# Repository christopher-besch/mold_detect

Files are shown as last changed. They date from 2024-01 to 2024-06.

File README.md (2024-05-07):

# mold_detect

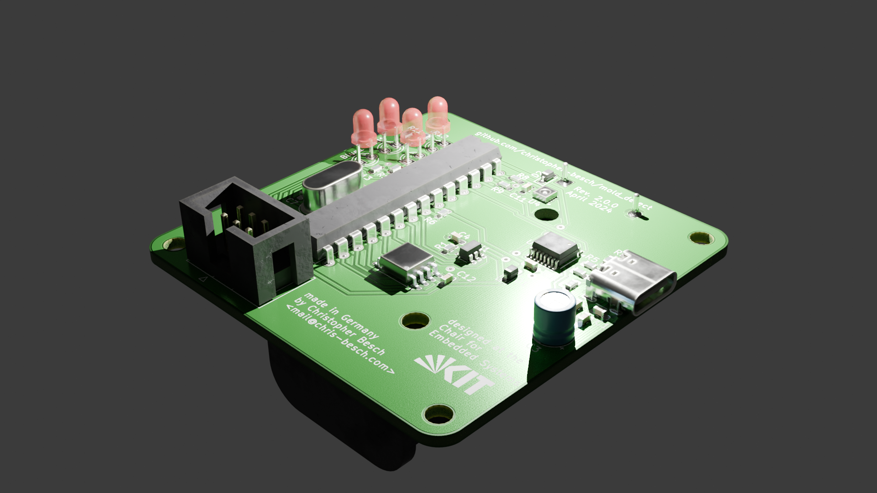
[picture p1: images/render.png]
3D render


Warn residents of mold-friendly atmosphere and log opened windows.

This project is being developed in AVR_C on an Atmega328p.
It provides:
- Temperature, Humidity Logging (every minute with flash storage for two years)
- LED warning to motivate the opening of windows or turnign on of heaters
- Serial terminal via USB-C
- ~5uA power consumption at 3V battery power

The PCB is designed in KiCad and manufactured by Aisler.

# Parts
- [TPL5010](https://www.digikey.de/de/products/detail/texas-instruments/TPL5010DDCR/5119105)
- [2 AAA Battery pack](https://www.digikey.de/de/products/detail/keystone-electronics/2468/303817)
- [SHT30](https://www.digikey.de/de/products/detail/sensirion-ag/SHT30-DIS-B2-5KS/5872250)
- [W25Q128JVSIQ](https://www.digikey.de/de/products/detail/winbond-electronics/W25Q128JVSIQ-TR/5803944)
- [FT230XS](https://www.digikey.de/en/products/detail/ftdi-future-technology-devices-international-ltd/FT230XS-R/3029141)
- [USB4105](https://www.digikey.de/en/products/detail/gct/USB4105-GF-A/11198441)

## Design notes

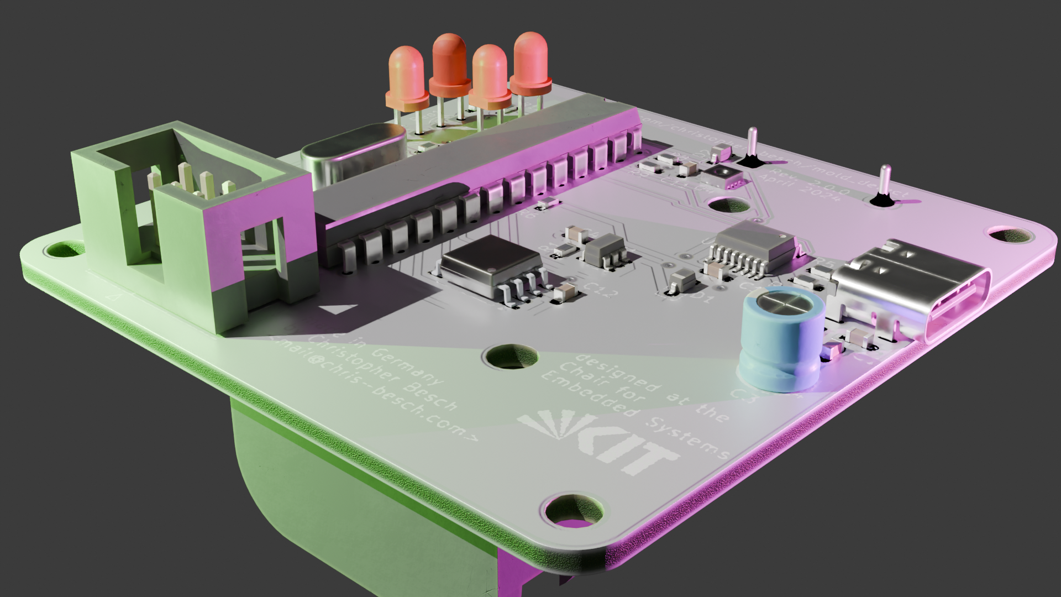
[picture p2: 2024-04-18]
images/color_render.png

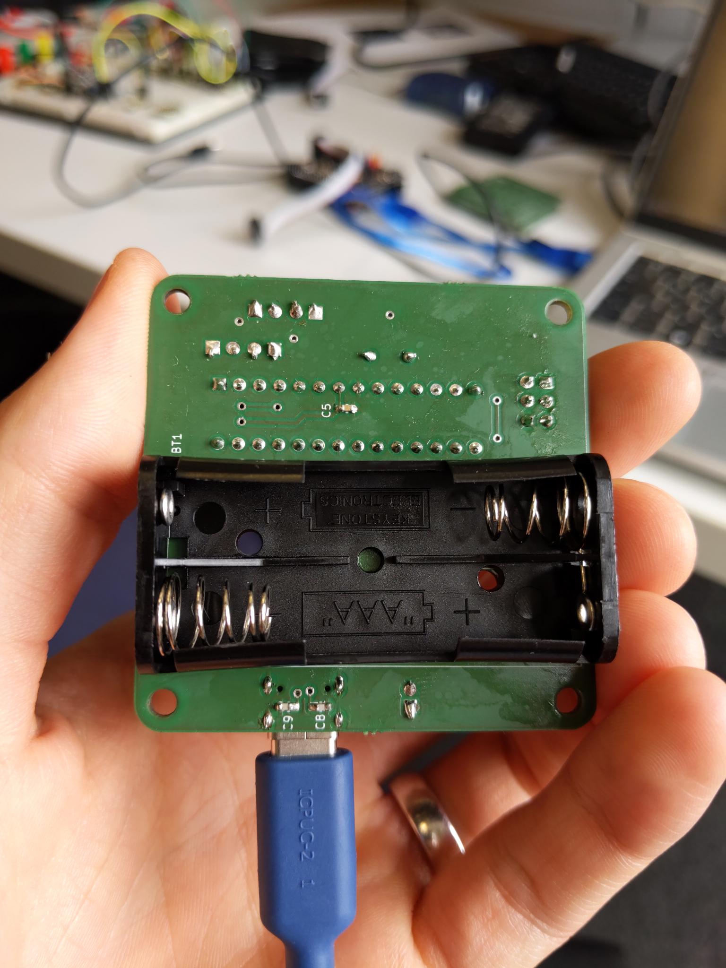
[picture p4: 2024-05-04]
images/back.jpeg

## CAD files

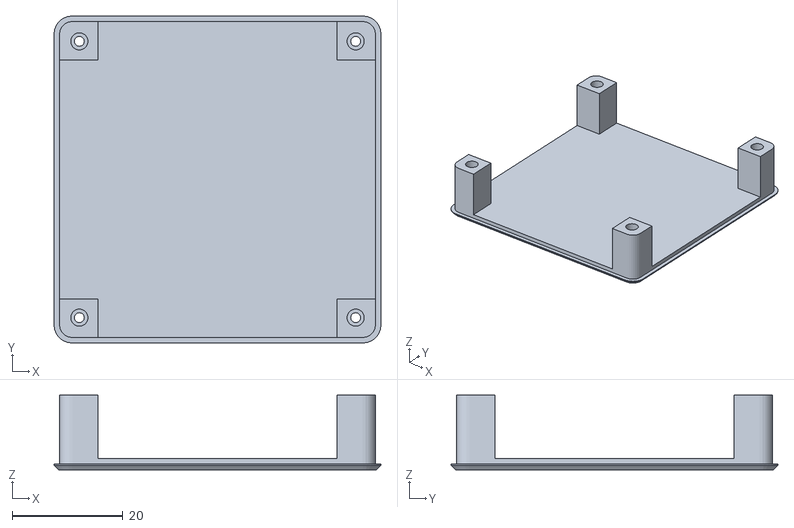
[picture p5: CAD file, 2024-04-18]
casing/bottom.stl
59.2 x 59.2 x 13.5

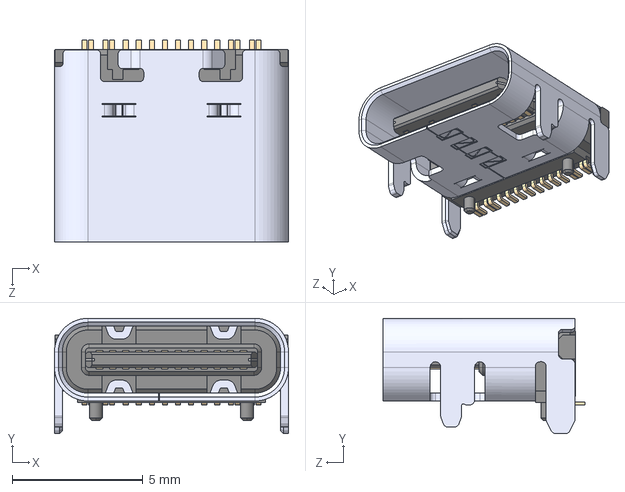
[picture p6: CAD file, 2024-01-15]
models/USB4105-GF-A.step
8.94 x 4.41 x 7.71 mm

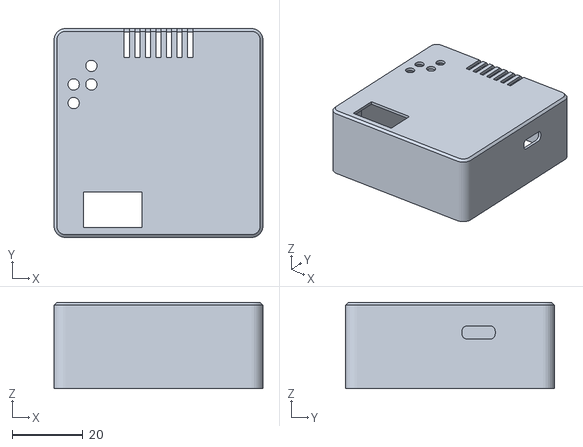
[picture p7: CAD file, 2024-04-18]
casing/top.stl
59.2 x 59.2 x 24.4

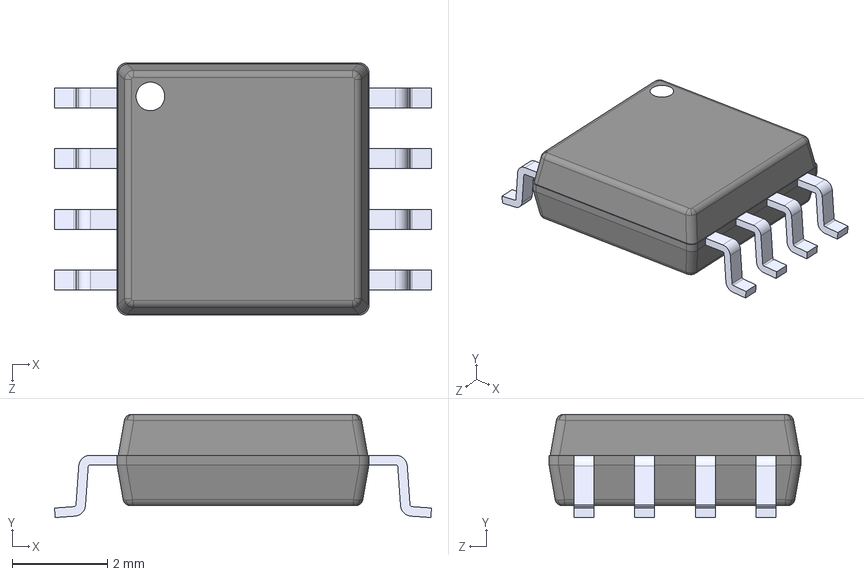
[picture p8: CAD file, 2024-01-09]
models/W25Q128JVSIQ_TR.step
7.90 x 2.16 x 5.28 mm

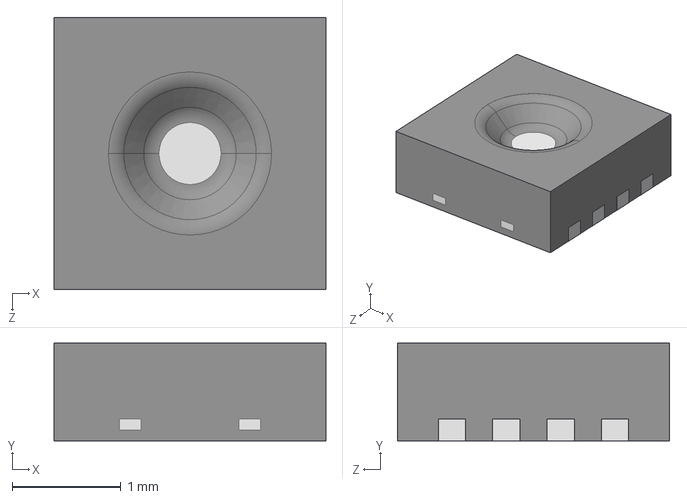
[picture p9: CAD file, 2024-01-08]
models/SHT30-DIS-B2.5KS.step
2.50 x 0.901 x 2.50 mm

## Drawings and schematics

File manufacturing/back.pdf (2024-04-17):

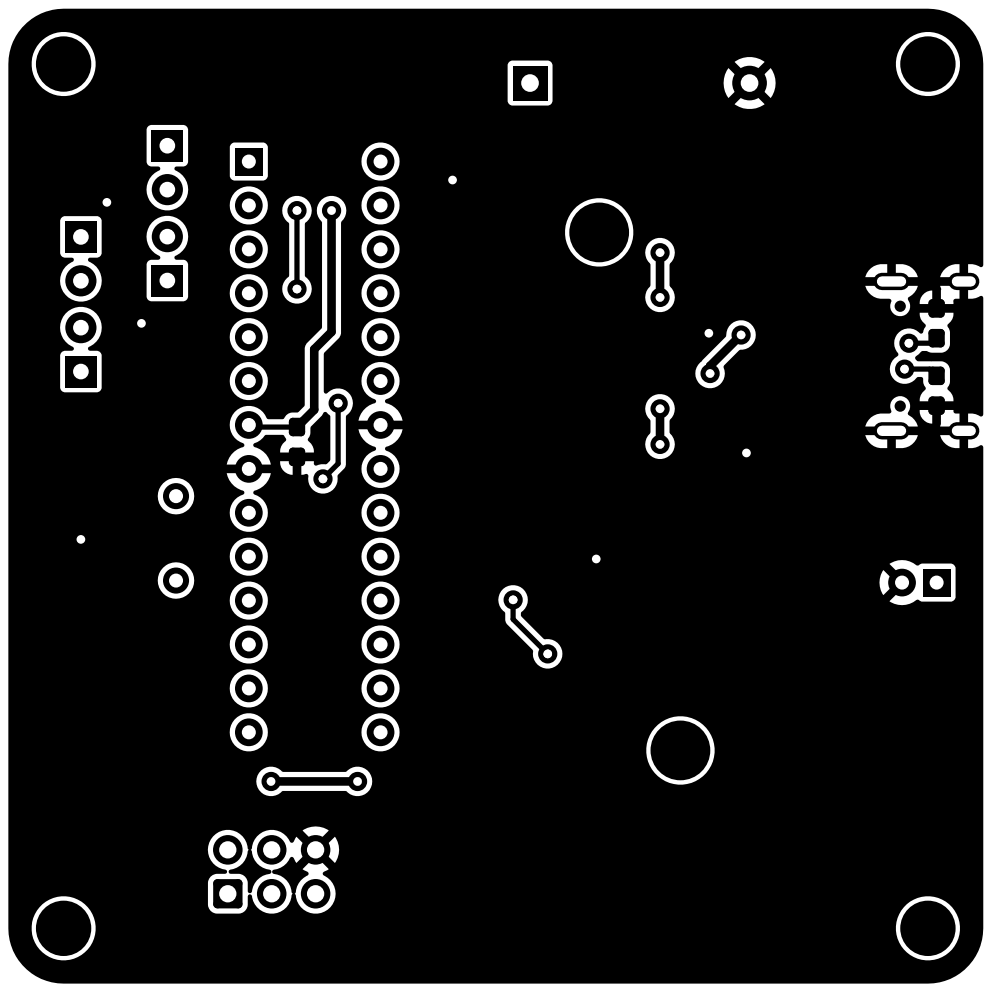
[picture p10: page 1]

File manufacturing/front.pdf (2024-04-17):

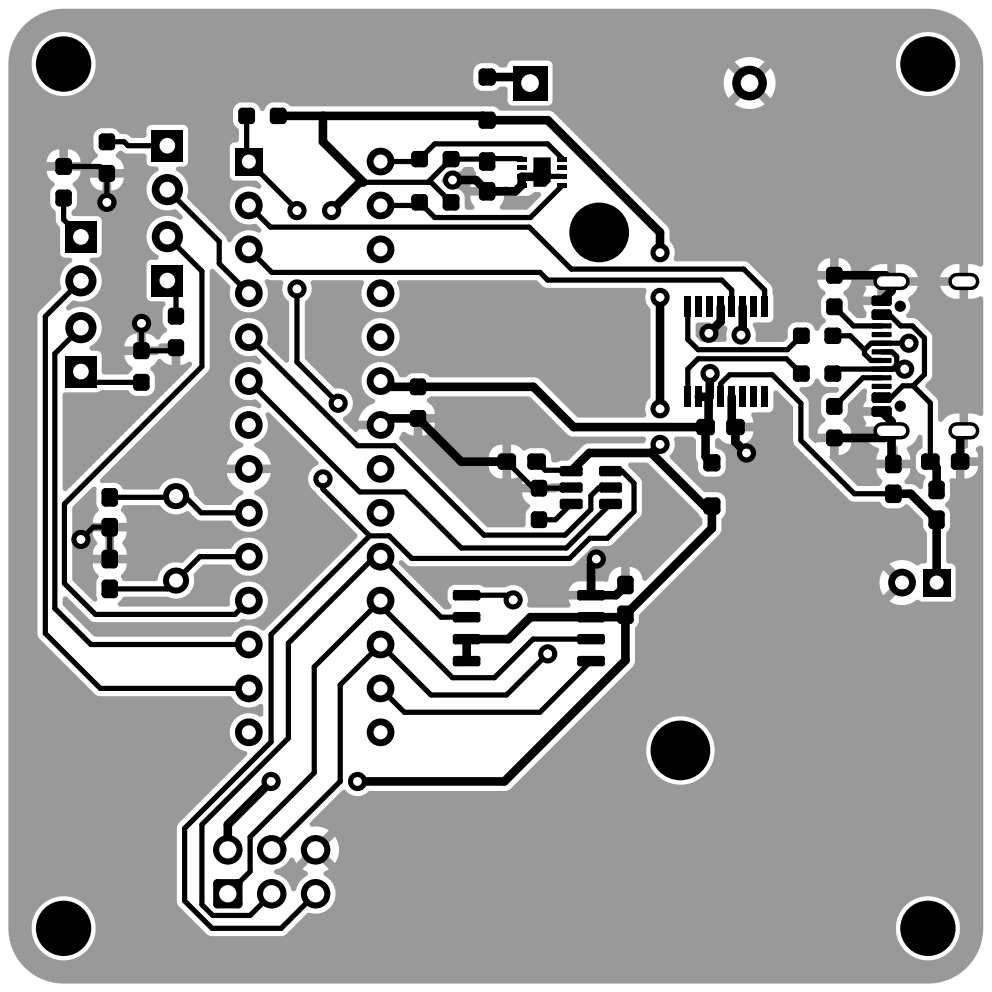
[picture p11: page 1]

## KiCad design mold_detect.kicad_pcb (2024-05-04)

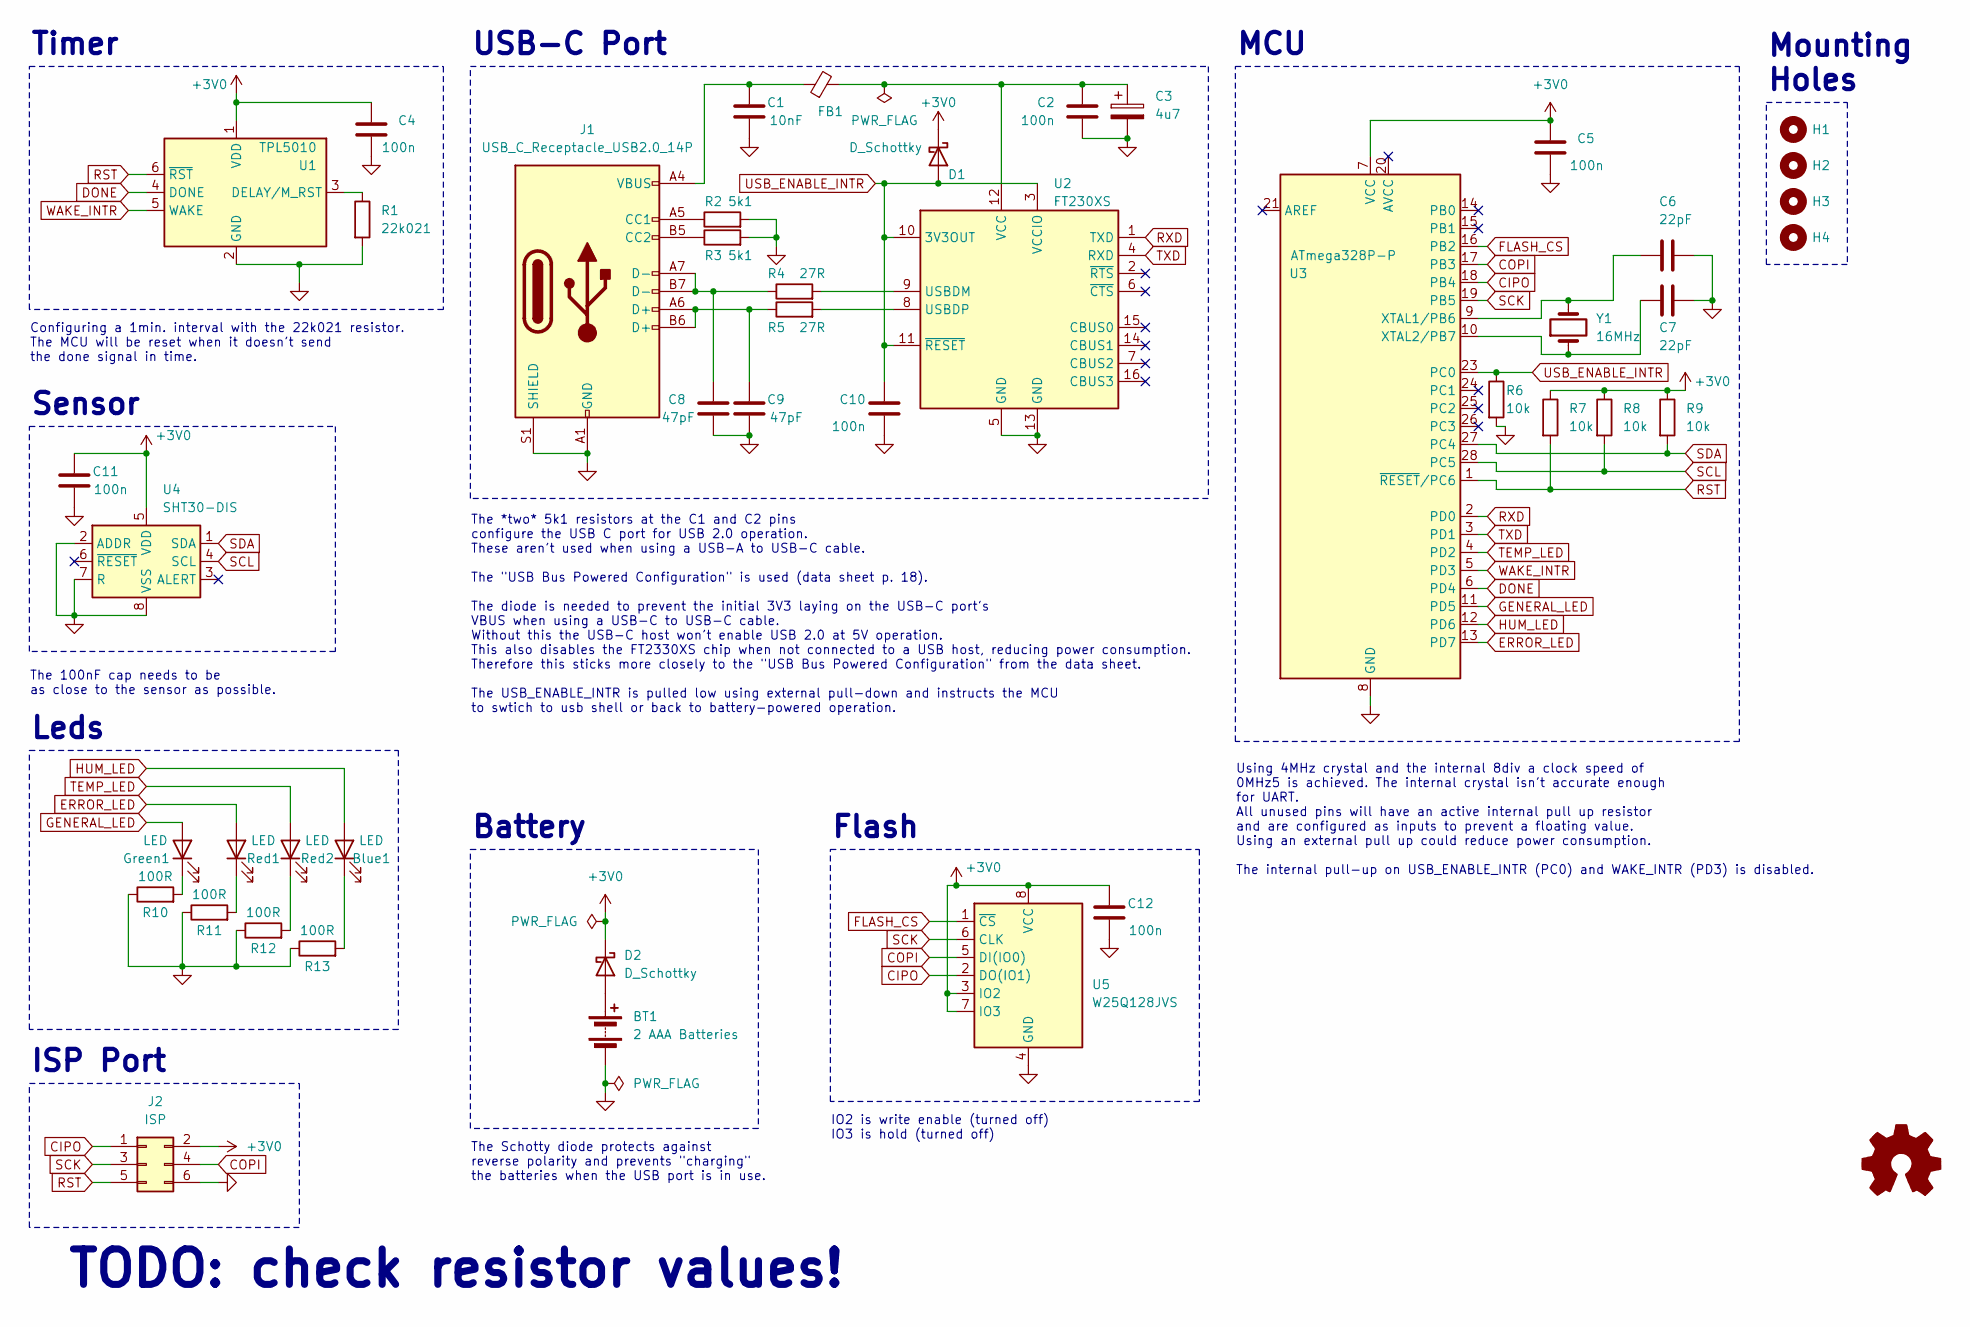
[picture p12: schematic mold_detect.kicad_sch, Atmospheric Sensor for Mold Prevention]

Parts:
BT1: 2 AAA Batteries; BatteryHolder_Keystone_2468_2xAAA
Blue1: LED; LED_D3.0mm
C1: 10nF; C_0603_1608Metric_Pad1.08x0.95mm_HandSolder
C2, C4, C5, C10, C11, C12: 100n; C_0603_1608Metric_Pad1.08x0.95mm_HandSolder
C3: 4u7; CP_Radial_D5.0mm_P2.00mm
C6, C7: 22pF; C_0603_1608Metric_Pad1.08x0.95mm_HandSolder
C8, C9: 47pF; C_0603_1608Metric_Pad1.08x0.95mm_HandSolder
D1, D2: D_Schottky; D_SOD-323_HandSoldering
FB1: C_0603_1608Metric_Pad1.08x0.95mm_HandSolder
Green1: LED; LED_D3.0mm
H1, H2, H3, H4: MountingHole_3.2mm_M3
J1: USB_C_Receptacle_USB2.0_14P; USB_C_Receptacle_GCT_USB4105-xx-A_16P_TopMnt_Horizontal
J2: ISP; IDC-Header_2x03_P2.54mm_Vertical
R1: 22k021; R_0603_1608Metric_Pad0.98x0.95mm_HandSolder
R2, R3: 5k1; R_0603_1608Metric_Pad0.98x0.95mm_HandSolder
R4, R5: 27R; R_0603_1608Metric_Pad0.98x0.95mm_HandSolder
R6, R7, R8, R9: 10k; R_0603_1608Metric_Pad0.98x0.95mm_HandSolder
R10, R11, R12, R13: 100R; R_0603_1608Metric_Pad0.98x0.95mm_HandSolder
Red1, Red2: LED; LED_D3.0mm
SYM1: github.com/christopher-besch/mold_detect; OSHW-Logo2_7.3x6mm_SilkScreen
U1: TPL5010; SOT-23-6
U2: FT230XS; SSOP-16_3.9x4.9mm_P0.635mm
U3: ATmega328P-P; DIP-28_W7.62mm
U4: SHT30-DIS; Sensirion_DFN-8-1EP_2.5x2.5mm_P0.5mm_EP1.1x1.7mm
U5: W25Q128JVS; SOIC-8_5.23x5.23mm_P1.27mm
Y1: 16MHz; Crystal_HC49-4H_Vertical

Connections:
+3V0: C4.2, C5.2, C11.2, C12.2, D1.1 (K), D2.1 (K), J2.2, R7.1, R8.1, R9.1, U1.1 (VDD), U3.7 (VCC), U4.5 (VDD), U5.3 (IO2), U5.7 (IO3), U5.8 (VCC)
CIPO: J2.1, U3.18 (PB4), U5.2 (DO(IO1))
COPI: J2.4, U3.17 (PB3), U5.5 (DI(IO0))
DONE: U1.4 (DONE), U3.6 (PD4)
ERROR_LED: Red1.2 (A), U3.13 (PD7)
FLASH_CS: U3.16 (PB2), U5.1 (~CS)
GENERAL_LED: Green1.2 (A), U3.11 (PD5)
GND: BT1.2 (-), C1.1, C2.1, C3.2, C4.1, C5.1, C6.1, C7.1, C8.1, C9.1, C10.1, C11.1, C12.1, J1.A1 (GND), J1.A12 (GND), J1.B1 (GND), J1.B12 (GND), J1.S1 (SHIELD), J2.6, R1.2, R2.2, R3.2, R6.2, R10.1, R11.1, R12.1, R13.1, U1.2 (GND), U2.5 (GND), U2.13 (GND), U3.8 (GND), U3.22 (GND), U4.2 (ADDR), U4.7 (R), U4.8 (VSS), U4.9 (VSS), U5.4 (GND)
HUM_LED: Blue1.2 (A), U3.12 (PD6)
unnamed: BT1.1 (+), D2.2 (A)
unnamed: Blue1.1 (K), R13.2
unnamed: C1.2, FB1.1, J1.A4 (VBUS), J1.A9 (VBUS), J1.B4 (VBUS), J1.B9 (VBUS)
unnamed: C8.2, J1.A7 (D-), J1.B7 (D-), R4.1
unnamed: C9.2, J1.A6 (D+), J1.B6 (D+), R5.1
unnamed: Green1.1 (K), R10.2
unnamed: J1.A5 (CC1), R2.1
unnamed: J1.B5 (CC2), R3.1
unnamed: R11.2, Red1.1 (K)
unnamed: R12.2, Red2.1 (K)
unnamed: R1.1, U1.3 (DELAY/M_RST)
unnamed: R4.2, U2.9 (USBDM)
unnamed: R5.2, U2.8 (USBDP)
unnamed: C2.2, C3.1, FB1.2, U2.12 (VCC)
unnamed: C6.2, U3.9 (XTAL1/PB6), Y1.2
unnamed: C7.2, U3.10 (XTAL2/PB7), Y1.1
RST: J2.5, R7.2, U1.6 (~RST), U3.1 (~RESET/PC6)
RXD: U2.1 (TXD), U3.2 (PD0)
SCK: J2.3, U3.19 (PB5), U5.6 (CLK)
SCL: R8.2, U3.28 (PC5), U4.4 (SCL)
SDA: R9.2, U3.27 (PC4), U4.1 (SDA)
TEMP_LED: Red2.2 (A), U3.4 (PD2)
TXD: U2.4 (RXD), U3.3 (PD1)
USB_ENABLE_INTR: C10.2, D1.2 (A), R6.1, U2.3 (VCCIO), U2.10 (3V3OUT), U2.11 (~RESET), U3.23 (PC0)
WAKE_INTR: U1.5 (WAKE), U3.5 (PD3)

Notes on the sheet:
ISP Port
Configuring a 1min. interval with the 22k021 resistor. The MCU will be reset when it doesn't send the done signal in time.
The 100nF cap needs to be as close to the sensor as possible.
TODO: check resistor values!
The *two* 5k1 resistors at the C1 and C2 pins configure the USB C port for USB 2.0 operation. These aren't used when using a USB-A to USB-C cable. The "USB Bus Powered Configuration" is used (data sheet p. 18). The diode is needed to prevent the initial 3V3 laying on the USB-C port's VBUS when usin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
Using 4MHz crystal and the internal 8div a clock speed of 0MHz5 is achieved. The internal crystal isn't accurate enough for UART. All unused pins will have an active internal pull up resistor and are configured as inputs to prevent a floating value. Using an external pull up could reduce power cons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
MCU
USB-C Port
Leds
IO2 is write enable (turned off) IO3 is hold (turned off)
Mounting Holes
The Schotty diode protects against reverse polarity and prevents "charging" the batteries when the USB port is in use.
Sensor
Flash
Timer
Battery

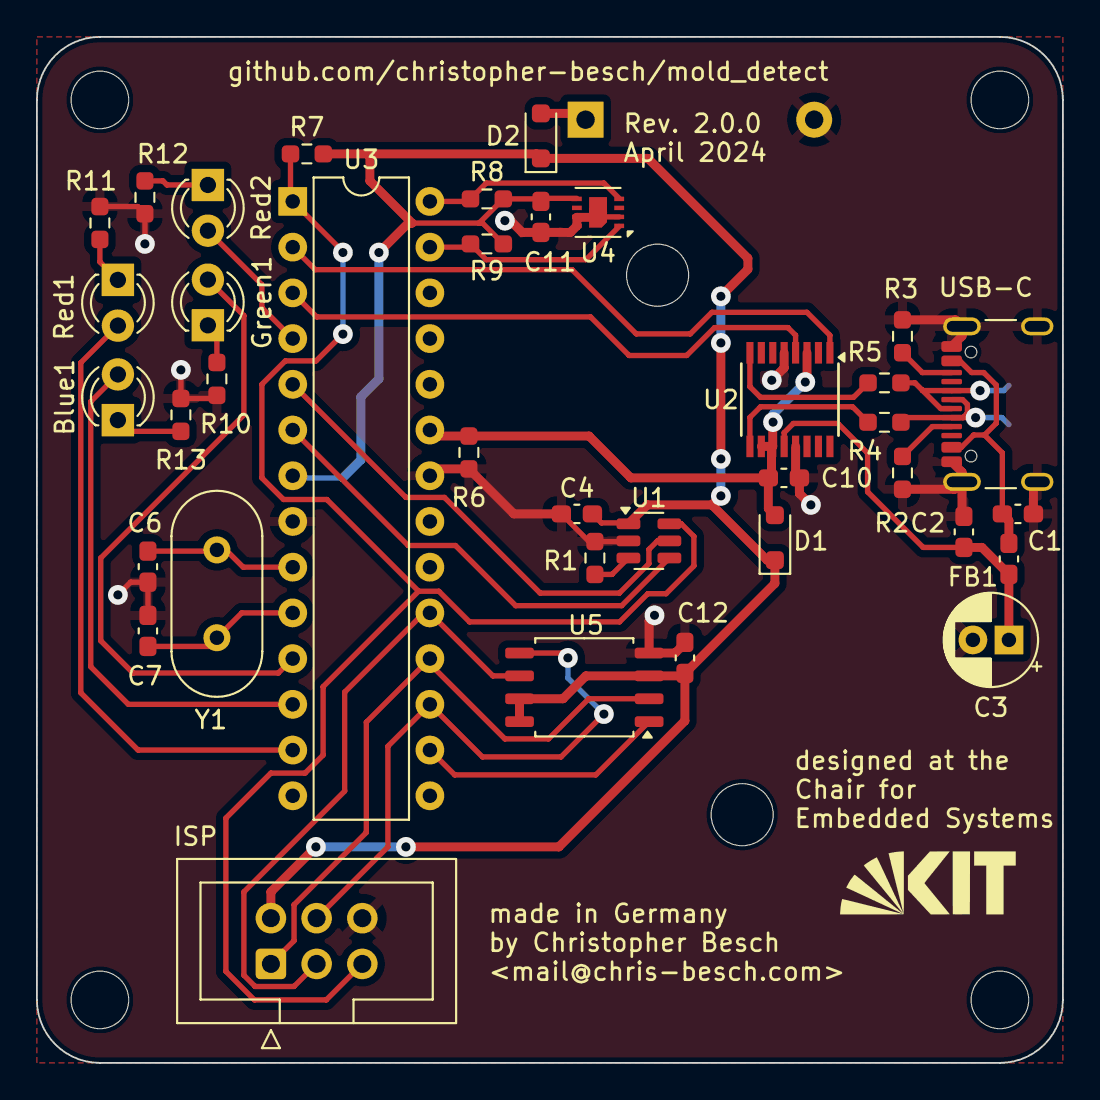
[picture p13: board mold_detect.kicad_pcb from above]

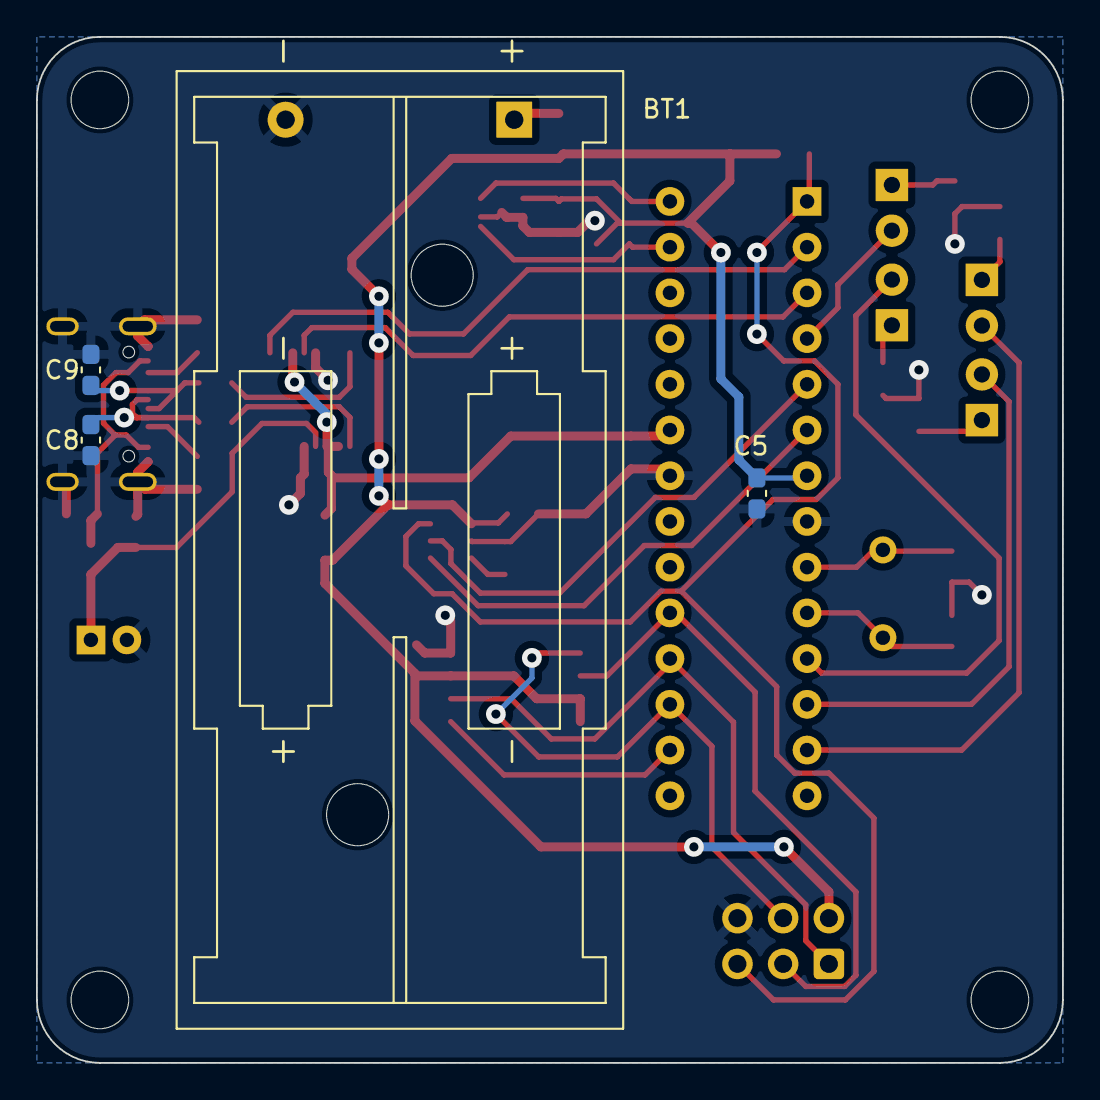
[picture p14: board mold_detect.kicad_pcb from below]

Board: 2 copper layers, 57.0 x 57.0 mm, 45 parts (4 on the bottom side), 34 nets.

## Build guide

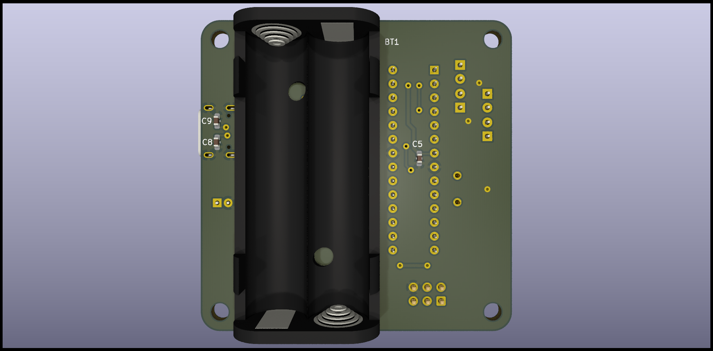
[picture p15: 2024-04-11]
manufacturing/mold_detect_back.png

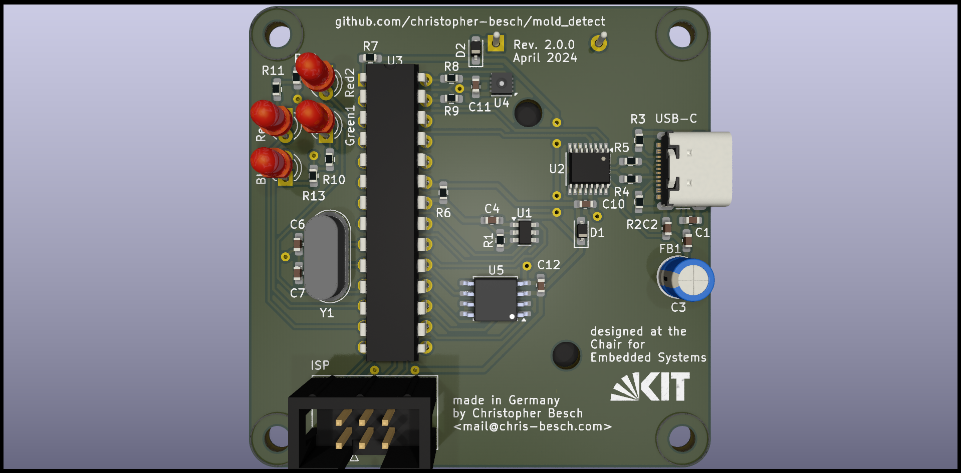
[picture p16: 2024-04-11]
manufacturing/mold_detect_front.png

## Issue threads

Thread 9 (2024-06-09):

make i2c measurement errors proper

christopher-besch, 2024-06-09:

Closed 2024-06-10.

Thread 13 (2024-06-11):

design heat set inserts

christopher-besch, 2024-06-11:
- [ ] remove current screw holes -> make pcb holder separate
- [ ] extend case to include separate screws to connect both 3d printed case parts

# Design Parameters as defined by @Tryskyfa
- 4.5mm diameter for heat set inserts
- 4mm heat set insert depth
- 8mm long screws

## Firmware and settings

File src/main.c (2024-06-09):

#include <avr/interrupt.h>
#include <avr/io.h>
#include <util/delay.h>

#include "flash.h"
#include "i2c.h"
#include "interrupts.h"
#include "led.h"
#include "terminal.h"
#include "uart.h"

void set_clock_speed()
{
    // see atmega328p docs 13.12.2 (p.60)
#if CLOCK_DIV == 1
    uint8_t clkps_3_0 = 0b0000;
#endif
#if CLOCK_DIV == 2
    uint8_t clkps_3_0 = 0b0001;
#endif
#if CLOCK_DIV == 4
    uint8_t clkps_3_0 = 0b0010;
#endif
#if CLOCK_DIV == 8
    uint8_t clkps_3_0 = 0b0011;
#endif
#if CLOCK_DIV == 16
    uint8_t clkps_3_0 = 0b0100;
#endif
#if CLOCK_DIV == 32
    uint8_t clkps_3_0 = 0b0101;
#endif
#if CLOCK_DIV == 64
    uint8_t clkps_3_0 = 0b0110;
#endif
#if CLOCK_DIV == 128
    uint8_t clkps_3_0 = 0b0111;
#endif
#if CLOCK_DIV == 256
    uint8_t clkps_3_0 = 0b1000;
#endif
    // enable updating the clock speed
    CLKPR = 1 << CLKPCE;
    // divide clock by whatever the preprocessor calculated
    CLKPR = clkps_3_0 << CLKPS0;
}

int main(void)
{
    set_clock_speed();

    // init //
    // the order here is very important as some subsystems rely on others to be initialized
    uart_init();
    // this should go as one of the first as the avr wdt might still be enabled
    interrupt_init();
    led_init();
    flash_init();
    i2c_init();

    set_atmosphere_led(1);
    uart_println("");
    uart_println("mold_detect booting up");
    print_version();
    _delay_ms(50);
    set_atmosphere_led(0);

    sei();
    // if you want uart for debugging, just enter the sleep cycle every time
    if(is_usb_mode())
        enter_terminal();
    else
        start_measurement_sleep_cycle();
}

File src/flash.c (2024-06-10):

#include "flash.h"
#include "error.h"
#include "flash_blocks.h"
#include "led.h"
#include "print.h"
#include "spi.h"
#include "uart.h"

#include <stdlib.h>
#include <util/delay.h>

// w25q128 instructions
#define FLASH_PAGE_PROGRAM    0x02
#define FLASH_READ_DATA       0x03
#define FLASH_READ_STATUS_REG 0x05
#define FLASH_WRITE_ENABLE    0x06
// 0x60 would also work
#define FLASH_CHIP_ERASE 0xc7
#define FLASH_POWER_DOWN 0xb9
#define FLASH_POWER_UP   0xab

#define FLASH_POWER_DOWN_DELAY_US 3
#define FLASH_POWER_UP_DELAY_US   3

static uint32_t          next_free_block_addr = 0;
static GenericFlashBlock block_buf;

uint8_t flash_is_full()
{
    return next_free_block_addr == FLASH_SIZE;
}

void flash_write_enable()
{
    spi_start();
    spi_transceive_char(FLASH_WRITE_ENABLE);
    spi_end();
}

int flash_is_busy()
{
    spi_start();
    spi_transceive_char(FLASH_READ_STATUS_REG);

    char reg1 = spi_receive_char();
    spi_end();

    return reg1 & (1 << 0);
}

void flash_await_write_completion()
{
    while(flash_is_busy())
        ;
}

void send_address(uint32_t address)
{
    // MSB address
    spi_transceive_char((address >> 0x10) & 0xff);
    spi_transceive_char((address >> 0x8) & 0xff);
    spi_transceive_char((address >> 0x0) & 0xff);
}

int flash_is_data_valid(uint32_t address, void* data, uint8_t nbytes)
{
    MD_ASSERT(data, MOLD_ERROR_INVALID_PARAMS_FLASH_IS_DATA_VALID_DATA_IS_NULL);

    spi_start();
    spi_transceive_char(FLASH_READ_DATA);
    send_address(address);

    for(uint8_t i = 0; i < nbytes; ++i) {
        if(((char*)data)[i] != spi_receive_char()) {
            spi_end();
            return 0;
        }
    }

    spi_end();
    return 1;
}

// write nbytes bytes from flash chip at address address to buf
// The flash chip may not be in power down mode
void flash_read_data(uint32_t address, void* buf, uint8_t nbytes)
{
    MD_ASSERT(buf, MOLD_ERROR_INVALID_PARAMS_FLASH_READ_DATA_BUF_IS_NULL);
    MD_ASSERT(address + nbytes <= FLASH_SIZE, MOLD_ERROR_INVALID_PARAMS_FLASH_READ_DATA_ADDRESS_OR_NBYTES_IS_TOO_HIGH);

    spi_start();
    spi_transceive_char(FLASH_READ_DATA);
    send_address(address);

    for(uint8_t i = 0; i < nbytes; ++i) {
        ((char*)buf)[i] = spi_receive_char();
    }

    spi_end();
}

// Write nbytes bytes from data to flash chip starting at address address.
// The area written to must be erased beforehand.
// The flash chip may not be in power down mode
// more than 256 bytes (one page) can't be written with one write command
//
// excerpt from data sheet p. 37:
//
// "If an entire 256 byte page is to be programmed, the last address byte (the 8 least significant address bits)
// should be set to 0. If the last address byte is not zero, and the number of clocks exceeds the remaining
// page length, the addressing will wrap to the beginning of the page. In some cases, less than 256 bytes (a
// partial page) can be programmed without having any effect on other bytes within the same page. One
// condition to perform a partial page program is that the number of clocks cannot exceed the remaining
// page length. If more than 256 bytes are sent to the device the addressing will wrap to the beginning of the
// page and overwrite previously sent data."
void flash_write_data(uint32_t address, void* data, uint8_t nbytes)
{
    MD_ASSERT(data, MOLD_ERROR_INVALID_PARAMS_FLASH_WRITE_DATA_DATA_IS_NULL);

    flash_write_enable();
    spi_start();

    spi_transceive_char(FLASH_PAGE_PROGRAM);
    send_address(address);

    for(uint8_t i = 0; i < nbytes; ++i) {
        spi_transceive_char(((char*)data)[i]);
    }

    spi_end();
    flash_await_write_completion();

    MD_ASSERT(flash_is_data_valid(address, data, nbytes), MOLD_ERROR_FLASH_WRITE_DATA_VALIDATION_FAILED);
}

void flash_read_block(uint32_t address, GenericFlashBlock* block)
{
    MD_ASSERT(block, MOLD_ERROR_INVALID_PARAMS_FLASH_READ_BLOCK_BLOCK_IS_NULL);
    // address needs to start at a block
    MD_ASSERT((address & FLASH_BLOCK_ADDR_MASK) == 0, MOLD_ERROR_INVALID_PARAMS_FLASH_READ_BLOCK_ADDRESS_DOESNT_START_AT_BLOCK);

    flash_read_data(address, block, sizeof(GenericFlashBlock));
}

void flash_write_block(uint32_t address, GenericFlashBlock* block)
{
    MD_ASSERT(block, MOLD_ERROR_INVALID_PARAMS_FLASH_WRITE_BLOCK_ADDRESS_BLOCK_IS_NULL);
    // address needs to start at a block
    MD_ASSERT((address & FLASH_BLOCK_ADDR_MASK) == 0, MOLD_ERROR_INVALID_PARAMS_FLASH_WRITE_BLOCK_ADDRESS_DOESNT_START_AT_BLOCK);

    flash_write_data(address, block, sizeof(GenericFlashBlock));
}

uint8_t is_block_free(uint32_t address)
{
    // address needs to start at a block
    MD_ASSERT((address & FLASH_BLOCK_ADDR_MASK) == 0, MOLD_ERROR_INVALID_PARAMS_IS_BLOCK_FREE_ADDRESS_DOESNT_START_AT_BLOCK);

    // this could be optimized by only reading the flag
    flash_read_block(address, &block_buf);

    return flash_is_block_free(block_buf.flags);
}

void flash_check_correct_free_block_addr()
{
    MD_ASSERT(flash_is_full() || is_block_free(next_free_block_addr), MOLD_ERROR_FLASH_CHECK_CORRECT_FREE_BLOCK_ADDR_NEXT_FREE_BLOCK_NOT_FREE);
    MD_ASSERT(next_free_block_addr == 0 || !is_block_free(next_free_block_addr - FLASH_BLOCK_SIZE), MOLD_ERROR_FLASH_CHECK_CORRECT_FREE_BLOCK_ADDR_BEFORE_NEXT_FREE_BLOCK_FREE);
}

// Perform a binary search to find the first free block.
void flash_find_next_free_block()
{
    // adapted from: https://www.geeksforgeeks.org/implementing-upper_bound-and-lower_bound-in-c/
    uint32_t mid;
    // the search window is [low, high)
    uint32_t low  = 0;
    uint32_t high = FLASH_BLOCKS_NUM;

    // until low is higher than high
    while(low < high) {
        mid = low + (high - low) / 2;

        if(is_block_free(mid * FLASH_BLOCK_SIZE))
            // use left subarray
            high = mid;
        else
            // use right subarray
            low = mid + 1;
    }

    // when even the last block is not free
    if(low < FLASH_BLOCKS_NUM && !is_block_free(low * FLASH_BLOCK_SIZE))
        ++low;

    next_free_block_addr = low * FLASH_BLOCK_SIZE;
    flash_check_correct_free_block_addr();
}

void flash_write_next_block(GenericFlashBlock* block)
{
    MD_ASSERT(block, MOLD_ERROR_INVALID_PARAMS_FLASH_WRITE_NEXT_BLOCK_BLOCK_IS_NULL);
    uart_println("writing block:");
    uart_print_flash_block(block, NULL);
    uart_println("");

    MD_ASSERT(!flash_is_full(), MOLD_ERROR_FLASH_WRITE_NEXT_BLOCK_FLASH_IS_FULL);
    flash_write_block(next_free_block_addr, block);

    // Check next_free_block_addr is found correctly.
    // The binary search is so fast we can effort this check.
    uint32_t expected_next_block = next_free_block_addr + FLASH_BLOCK_SIZE;
    flash_find_next_free_block();
    MD_ASSERT(next_free_block_addr == expected_next_block, MOLD_ERROR_FLASH_WRITE_NEXT_BLOCK_FIND_NEXT_FREE_BLOCK_FAILED);
}
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

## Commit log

2024-01-08 added ces reference; moved sensor to bottom
    [mold_detect.kicad_pcb, mold_detect.kicad_sch]
2024-01-08 better clearances
    [mold_detect.kicad_pcb]
2024-01-08 added new gerber files
    [mold_detect-B_Cu.gbr, mold_detect-B_Mask.gbr, mold_detect-B_Paste.gbr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]
2024-01-09 removed isp; added uart; added flash
    [W25Q128JVSIQ_TR.step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]
2024-01-15 added usb c port
    [USB4105-GF-A.step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]
2024-01-22 changed usb-c port to match "USB Bus Powered Configuration" from p. 18
    [mold_detect.kicad_sch]
2024-01-31 added external oscillator
    [mold_detect.kicad_sch]
2024-04-08 the spi flash chip works
    [mold_detect.kicad_pcb, mold_detect.kicad_sch]
2024-04-10 temp/hum sensor works!
    [mold_detect.kicad_sch]
2024-04-10 tpl5010 works!
    [mold_detect.kicad_pcb, mold_detect.kicad_sch]
2024-04-11 updated footprints; started layout
    [mold_detect.kicad_pcb, mold_detect.kicad_sch]
2024-04-11 updated PCB design
    [mold_detect-B_Cu.gbr, mold_detect-B_Mask.gbr, mold_detect-B_Paste.gbr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]
2024-04-17 added blender
    [mold_detect-B_Cu.gbr, mold_detect-B_Mask.gbr, mold_detect-B_Paste.gbr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]
2024-04-18 added temp pdf
    [mold_detect.kicad_pcb]
2024-04-18 added stl files
    [bottom.stl, top.stl]
2024-04-18 added battery holder to 3d print
    [bottom.stl, mold_detect.kicad_pcb, top.stl]
2024-04-18 before removing gnd connections
    [mold_detect-B_Cu.gbr, mold_detect-B_Mask.gbr, mold_detect-B_Paste.gbr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]
2024-04-18 ready to order pcb
    [mold_detect-B_Cu.gbr, mold_detect-B_Mask.gbr, mold_detect-B_Paste.gbr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]
2024-05-04 added structs for flash
    [mold_detect.kicad_pcb]
2024-05-05 using macros for pin names for interrupts
2024-05-06 fixed avr-size in Makefile and fixed should_measure = 1
    [interrupts.c, main.c]
2024-06-07 feat: added atmosphere_bad and error flag; created constructors for flash blocks
    [flash.c, i2c.c, measure.c]
2024-06-07 feat: implemented flash readout
    This also fixes calling `flash_write_data` with a pointer pointer
    instead of a straight pointer.
    closes #3
    [flash.c, i2c.c, measure.c]
2024-06-08 fix: small grammar fixes and comments
    [flash.c, terminal.c]
2024-06-08 fix: better function names
    [interrupts.c, measure.c, terminal.c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]
2024-06-08 feat: split uart functions into uart and print
2024-06-09 feat: proper clock speed calculation
    This fixes the i2c measurement errors by reducing the i2c speed.
    This also sends an i2c stop condition after an i2c failure.
    [i2c.c, main.c, measure.c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]
2024-06-09 fix: fixed 256 div factor value
    [i2c.c, main.c]
2024-06-09 feat: implemented flash power down
    closes #1
    [mold_detect.kicad_sch]
2024-06-10 fix: proper errors in measurement
    closes #9
    [flash.c, i2c.c, measure.c]
2024-06-10 fix: fixed measure error state
    [measure.c]
2024-06-11 feat(case): using nut for battery
    closes #11
